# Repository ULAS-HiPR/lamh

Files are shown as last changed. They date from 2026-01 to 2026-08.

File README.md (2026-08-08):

# Lámh

Lámh is the airbrake actuator node in [Ogma](https://sean-osullivan.com/projects/ogma/), the University of Limerick Aeronautics Society's modular avionics stack for high-powered rocketry.

## Role

- Drives four routed servo outputs through a PCA9685.
- Reads a physical arm input.
- Accepts time-limited actuator commands over the 500 kbit/s CAN bus.
- Enforces defined safe states when commands expire or communication is lost.

## Repository

- `hardware/` - KiCad design and manufacturing outputs.
- `firmware/` - embedded firmware, actuator probes, and tests.

## Status

Rev 1 firmware and hardware bring-up continue on [`ogma/flight-hardening`](https://github.com/ULAS-HiPR/lamh/tree/ogma/flight-hardening). Release-candidate firmware builds and software tests pass, but hardware-in-the-loop validation is still underway. Lámh is not yet flight-proven.

## Manufacturing support

Rev 1 PCB fabrication was sponsored through [EasyEDA Education](https://easyeda.com/education) and manufactured by [JLCPCB](https://jlcpcb.com/). The board was designed in KiCad and imported into EasyEDA Pro for the sponsorship and manufacturing workflow.

## More information

See the [Ogma project write-up](https://sean-osullivan.com/projects/ogma/) for the complete stack, bring-up work, and current status.

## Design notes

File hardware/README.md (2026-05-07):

# Hardware Notes

## PCA9685 servo outputs

The current Lamh PCB routes the PCA9685 outputs to four servo connectors:

| Connector | PCA9685 channel | Connector pin 1 | Connector pin 2 | Connector pin 3 |
| --- | ---: | --- | --- | --- |
| J4 | 0 | Signal | GND | 5v_SERVO |
| J6 | 2 | Signal | GND | 5v_SERVO |
| J2 | 4 | Signal | GND | 5v_SERVO |
| J3 | 6 | Signal | GND | 5v_SERVO |

The firmware demo currently sweeps channel 0, so plug the demo servo into J4.

## PCA9685 address

A0-A3 have pulldowns and solder jumpers to 3.3 V. For the default `0x40` address, leave those jumpers open. The firmware scans the PCA9685 hardware-address range at boot, so changed address jumpers should still work.

A4 and A5 are marked unconnected in the current PCB files. If I2C probing is unstable on a built board, strap U2 A4 and A5 low for a deterministic `0x40` address in the next hardware revision.

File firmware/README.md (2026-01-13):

# Lamh

Lamh is for any active control like airbrakes or canards. It will control servos.

## Set-Up

```bash
git clone git@github.com:ULAS-HiPR/lamh.git
cd lamh
git submodule update --init --recursive
```

## Libraries used:

### From Braiteoiri:

- Servo
- LED

### From Comheadan:

- CAN
- PWM

### Other:

- FreeRTOS

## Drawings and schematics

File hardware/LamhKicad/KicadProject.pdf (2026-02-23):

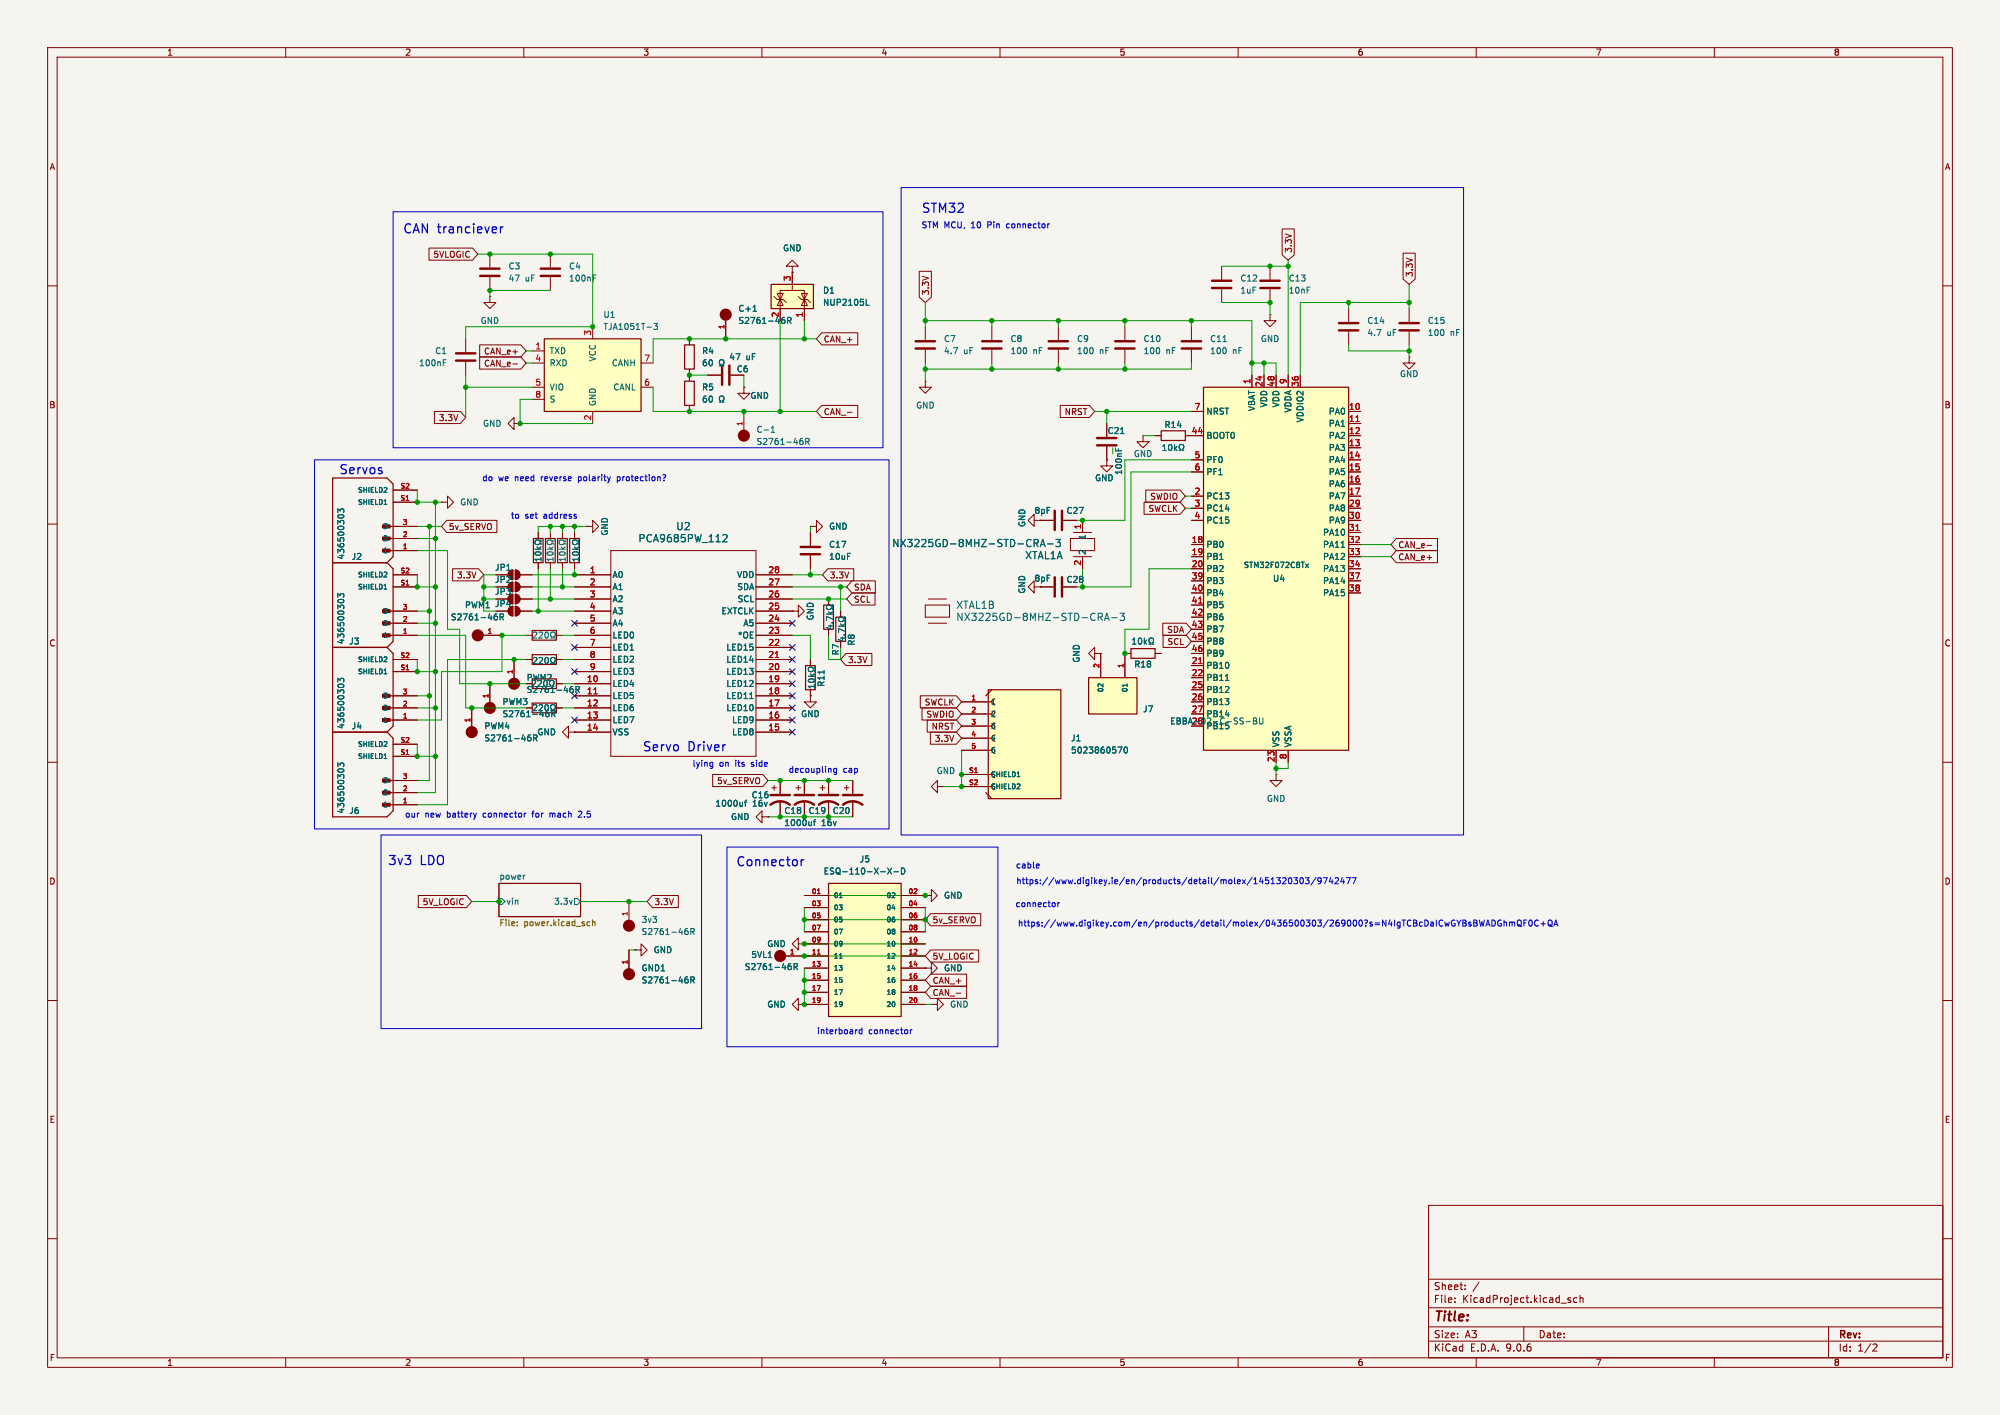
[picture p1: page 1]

STM32
STM MCU, 10 Pin connector

1 VDD 24 VDD 48 VSS 23 VDDA

1 GND R7 þÿ4.7k© R8þÿ4.7k© R11 þÿ10k© GND

lying on its side
1 GND GND

https://www.digikey.ie/en/products/detail/molex/1451320303/9742477

https://www.digikey.com/en/products/detail/molex/0436500303/269000?s=N4IgTCBcDaICwGYBsBWADGhmQF0C+QA

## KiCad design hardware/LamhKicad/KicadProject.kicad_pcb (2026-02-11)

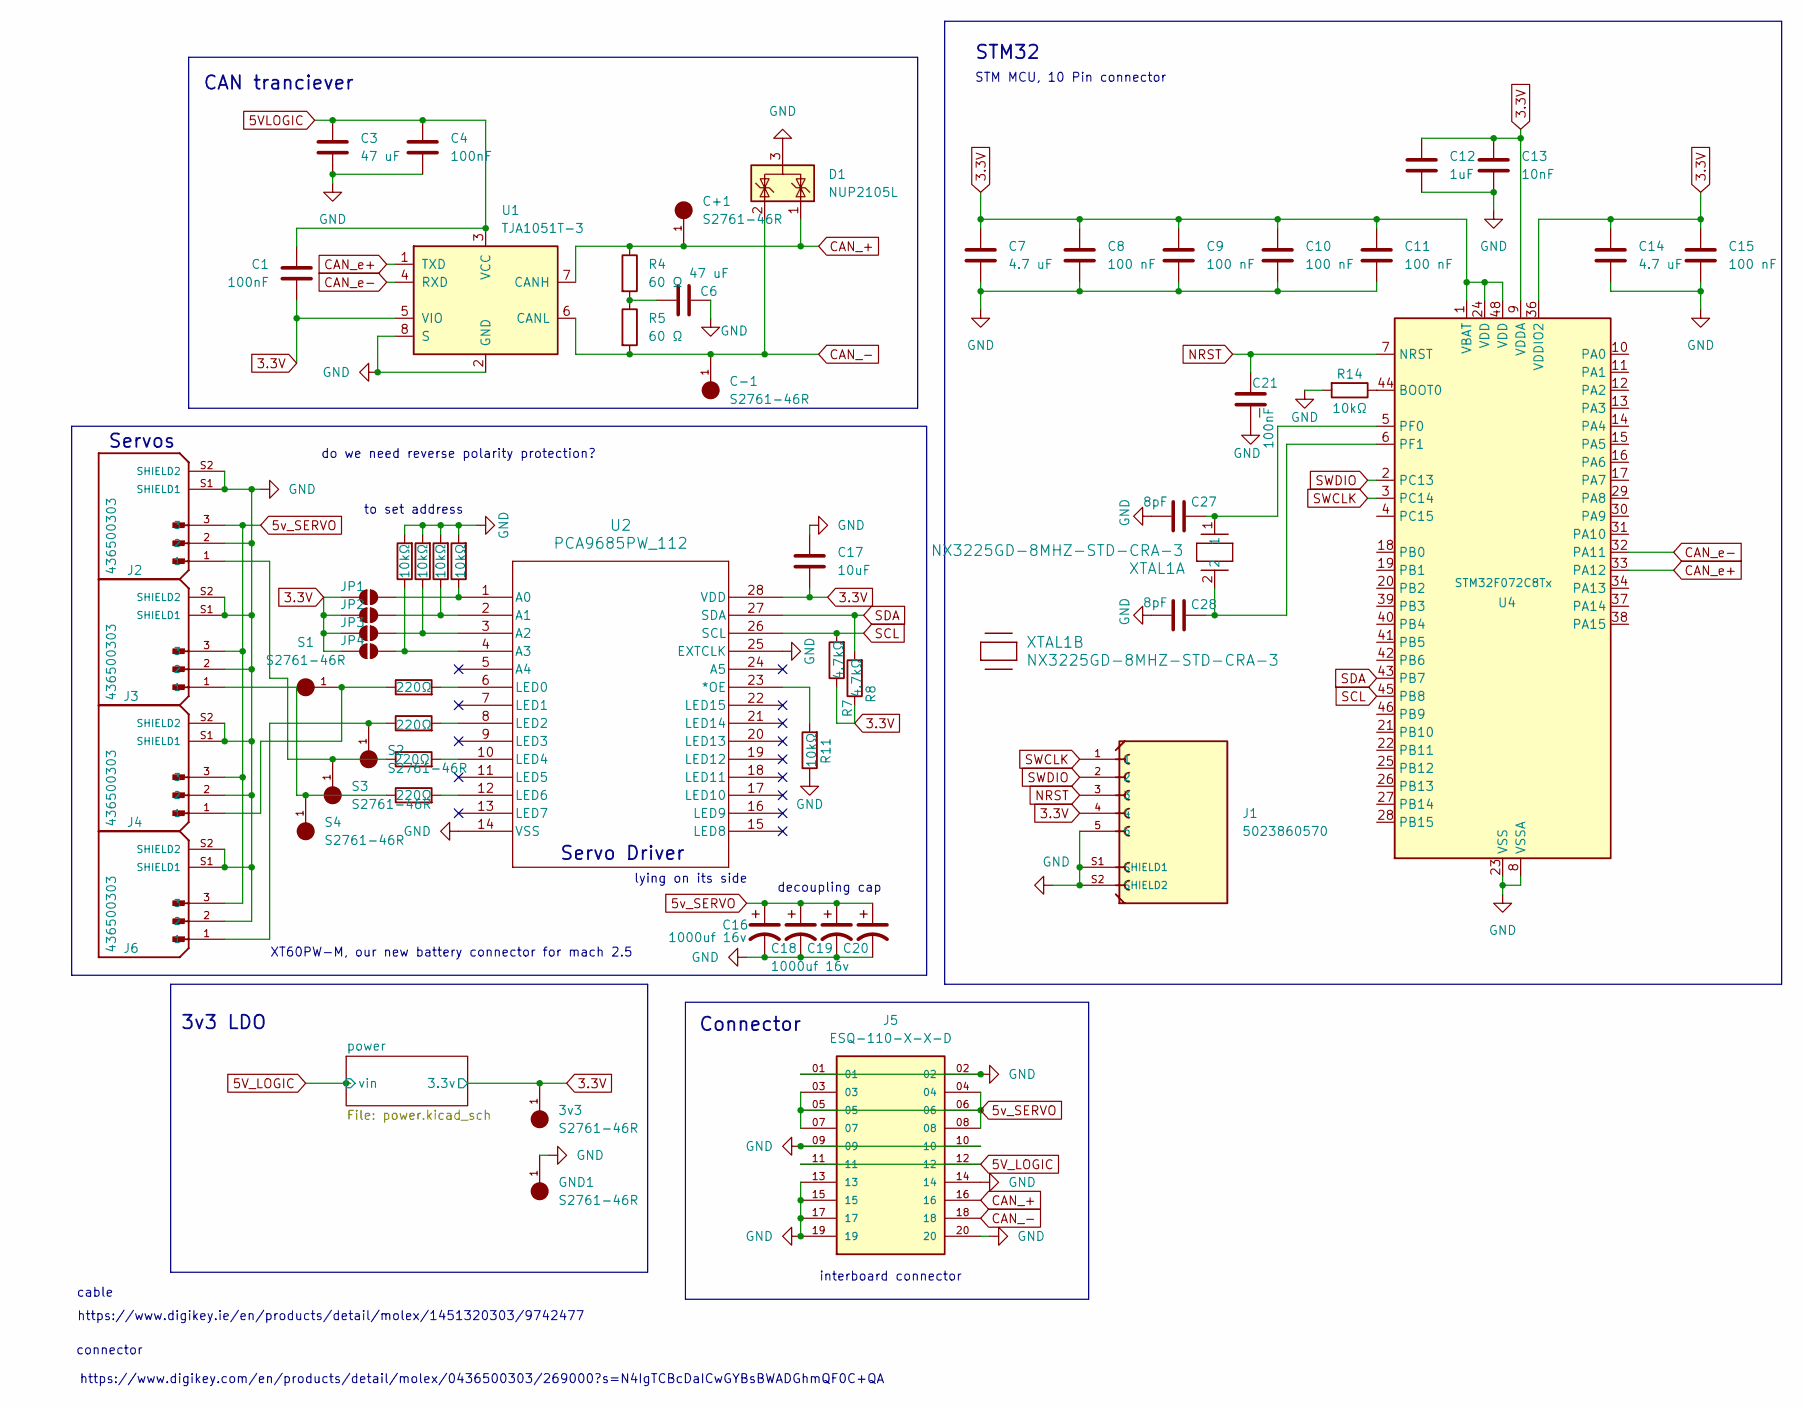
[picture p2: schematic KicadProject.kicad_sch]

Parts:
3v3: S2761-46R; HARWIN_S2761-46R; PARTREV 1
C1, C4, C21: 100nF; C_0402_1005Metric
C3, C6: 47 uF; C_0402_1005Metric
C7, C14: 4.7 uF; C_0402_1005Metric
C8, C9, C10, C11, C15: 100 nF; C_0402_1005Metric
C12: 1uF; C_0402_1005Metric
C13: 10nF; C_0402_1005Metric
C16, C18, C19, C20: 1000uf 16v; CP_Radial_D10.0mm_P5.00mm
C17: 10uF; C_0402_1005Metric
C27, C28: 8pF; C_0402_1005Metric
C+1: S2761-46R; HARWIN_S2761-46R; PARTREV 1
C-1: S2761-46R; HARWIN_S2761-46R; PARTREV 1
D1: NUP2105L; SOT-23
GND1: S2761-46R; HARWIN_S2761-46R; PARTREV 1
J1: 5023860570; MOLEX_5023860570; PARTREV F
J2, J3, J4, J6: 436500303; MOLEX_436500303; PARTREV F3
J5: ESQ-110-X-X-D; SAMTEC_ESQ-110-14-G-D; PARTREV NA
JP1, JP2, JP3, JP4: SolderJumper_2_Open; SolderJumper-2_P1.3mm_Open_TrianglePad1.0x1.5mm
R1, R2, R3, R6: 220Ω; R_0402_1005Metric
R4, R5: 60 Ω; R_0402_1005Metric
R7, R8: 4.7kΩ; R_0402_1005Metric
R9, R10, R11, R12, R13, R14: 10kΩ; R_0402_1005Metric
S1, S2, S3, S4: S2761-46R; HARWIN_S2761-46R; PARTREV 1
U1: TJA1051T-3; SOIC-8_3.9x4.9mm_P1.27mm
U2: PCA9685PW_112; TSSOP28_SOT361-1_NXP
U4: STM32F072C8Tx; LQFP-48_7x7mm_P0.5mm
XTAL1: NX3225GD-8MHZ-STD-CRA-3; XTAL_NX3225GD-8MHZ-STD-CRA-3_NDK

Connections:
3.3V: 3v3.1, C1.1, C7.1, C8.1, C9.1, C10.1, C11.1, C12.1, C13.1, C14.1, C15.1, C17.2, J1.4, JP1.1 (A), JP2.1 (A), JP3.1 (A), JP4.1 (A), R7.1, R8.1, U1.5 (VIO), U2.28 (VDD), U4.1 (VBAT), U4.9 (VDDA), U4.24 (VDD), U4.36 (VDDIO2), U4.48 (VDD); also elsewhere on the board
5VLOGIC: C1.2, C3.1, C4.1, U1.3 (VCC)
5V_LOGIC: J5.11, J5.12; also elsewhere on the board
5v_SERVO: C16.1, C18.1, C19.1, C20.1, J2.3, J3.3, J4.3, J5.03, J5.04, J5.05, J5.06, J5.07, J5.08, J6.3
CAN_+: C+1.1, D1.1 (K), J5.16, R4.1, U1.7 (CANH)
CAN_-: C-1.1, D1.2 (K), J5.18, R5.2, U1.6 (CANL)
CAN_e+: U1.1 (TXD), U4.33 (PA12)
CAN_e-: U1.4 (RXD), U4.32 (PA11)
GND: C3.2, C4.2, C6.2, C7.2, C8.2, C9.2, C10.2, C11.2, C12.2, C13.2, C14.2, C15.2, C16.2, C17.1, C18.2, C19.2, C20.2, C21.2, C27.1, C28.2, D1.3 (A), GND1.1, J1.5, J1.S1 (SHIELD1), J1.S2 (SHIELD2), J2.2, J2.S1 (SHIELD1), J2.S2 (SHIELD2), J3.2, J3.S1 (SHIELD1), J3.S2 (SHIELD2), J4.2, J4.S1 (SHIELD1), J4.S2 (SHIELD2), J5.01, J5.02, J5.09, J5.10, J5.13, J5.14, J5.15, J5.17, J5.19, J5.20, J6.2, J6.S1 (SHIELD1), J6.S2 (SHIELD2), R9.2, R10.2, R11.1, R12.2, R13.2, R14.2, U1.2 (GND), U1.8 (S), U2.14 (VSS), U2.25 (EXTCLK), U4.8 (VSSA), U4.23 (VSS), U4.35 (VSS), U4.47 (VSS); also elsewhere on the board
NRST: C21.1, J1.3, U4.7 (NRST)
unnamed: C6.1, R4.2, R5.1
unnamed: J2.1, R3.1, S3.1
unnamed: J3.1, R6.1, S4.1
unnamed: J4.1, R1.1, S1.1
unnamed: J6.1, R2.1, S2.1
unnamed: JP1.2 (B), R9.1, U2.1 (A0)
unnamed: JP2.2 (B), R10.1, U2.2 (A1)
unnamed: JP3.2 (B), R12.1, U2.3 (A2)
unnamed: JP4.2 (B), R13.1, U2.4 (A3)
unnamed: R11.2, U2.23 (*OE)
unnamed: R1.2, U2.6 (LED0)
unnamed: R2.2, U2.8 (LED2)
unnamed: R3.2, U2.10 (LED4)
unnamed: R6.2, U2.12 (LED6)
unnamed: R14.1, U4.44 (BOOT0)
unnamed: C27.2, U4.5 (PF0), XTAL1.1
unnamed: C28.1, U4.6 (PF1), XTAL1.2
SCL: R7.2, U2.26 (SCL), U4.45 (PB8)
SDA: R8.2, U2.27 (SDA), U4.43 (PB7)
SWCLK: J1.1, U4.3 (PC14)
SWDIO: J1.2, U4.2 (PC13)

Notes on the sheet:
Servo Driver
Servos
interboard connector
cable
3v3 LDO
CAN tranciever
STM32
decoupling cap
XT60PW-M, our new battery connector for mach 2.5
https://www.digikey.com/en/products/detail/molex/0436500303/269000?s=N4IgTCBcDaICwGYBsBWADGhmQF0C+QA
https://www.digikey.ie/en/products/detail/molex/1451320303/9742477
connector
Connector
lying on its side
to set address
do we need reverse polarity protection?
STM MCU, 10 Pin connector

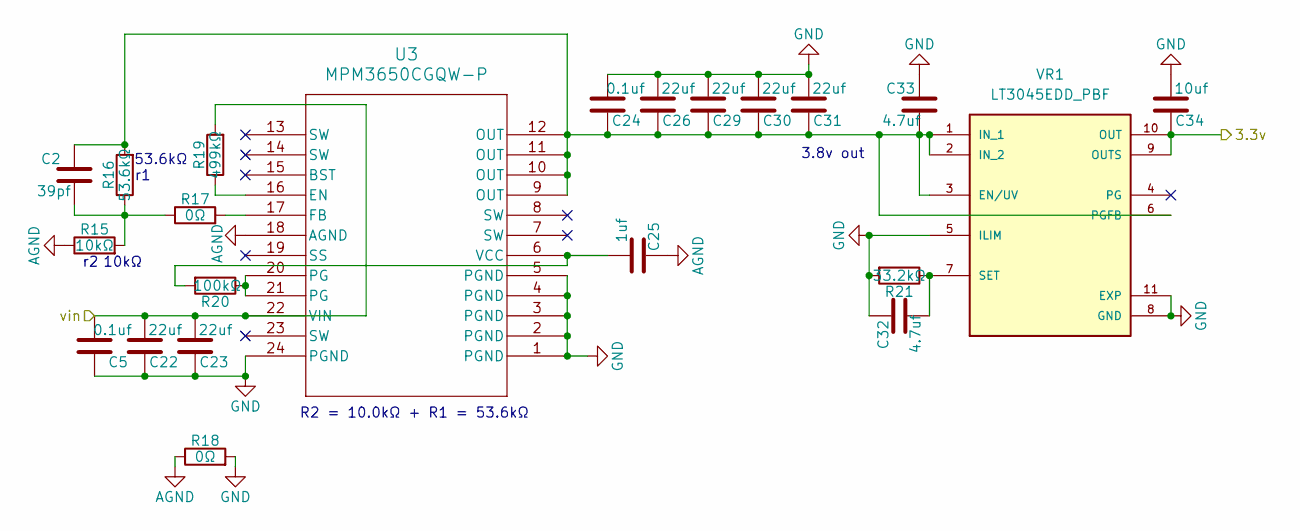
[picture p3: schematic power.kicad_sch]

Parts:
C2: 39pf; C_0402_1005Metric
C5, C24: 0.1uf; C_0402_1005Metric
C22, C23, C26, C29, C30, C31: 22uf; C_0402_1005Metric
C25: 1uf; C_0402_1005Metric
C32, C33: 4.7uf; C_0402_1005Metric
C34: 10uf; C_0402_1005Metric
R15: 10kΩ; R_0402_1005Metric
R16: 53.6kΩ; R_0402_1005Metric
R17, R18: 0Ω; R_0402_1005Metric
R19: 499kΩ; R_0402_1005Metric
R20: 100kΩ; R_0402_1005Metric
R21: 33.2kΩ; R_0402_1005Metric
U3: MPM3650CGQW-P; QFN-24_MPM3650_MNP
VR1: LT3045EDD_PBF; SON50P300X300X80-11N; PARTREV C

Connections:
3.3V: C34.1, VR1.9 (OUTS), VR1.10 (OUT); also elsewhere on the board
5V_LOGIC: C5.2, C22.2, C23.2, R19.2, U3.22 (VIN); also elsewhere on the board
AGND: C25.1, R15.1, R18.1, U3.18 (AGND)
GND: C5.1, C22.1, C23.1, C24.2, C26.2, C29.2, C30.2, C31.2, C32.1, C33.1, C34.2, R18.2, R21.2, U3.1 (PGND), U3.2 (PGND), U3.3 (PGND), U3.4 (PGND), U3.5 (PGND), U3.24 (PGND), VR1.5 (ILIM), VR1.8 (GND), VR1.11 (EXP); also elsewhere on the board
unnamed: C2.2, R15.2, R16.1, R17.1
unnamed: R20.1, U3.20 (PG), U3.21 (PG)
unnamed: R19.1, U3.16 (EN)
unnamed: R17.2, U3.17 (FB)
unnamed: C25.2, R20.2, U3.6 (VCC)
unnamed: C2.1, C24.1, C26.1, C29.1, C30.1, C31.1, C33.2, R16.2, U3.9 (OUT), U3.10 (OUT), U3.11 (OUT), U3.12 (OUT), VR1.1 (IN_1), VR1.2 (IN_2), VR1.3 (EN/UV), VR1.6 (PGFB)
unnamed: C32.2, R21.1, VR1.7 (SET)

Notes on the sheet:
10kΩ
53.6kΩ
R2 = 10.0kΩ + R1 = 53.6kΩ
3.8v out

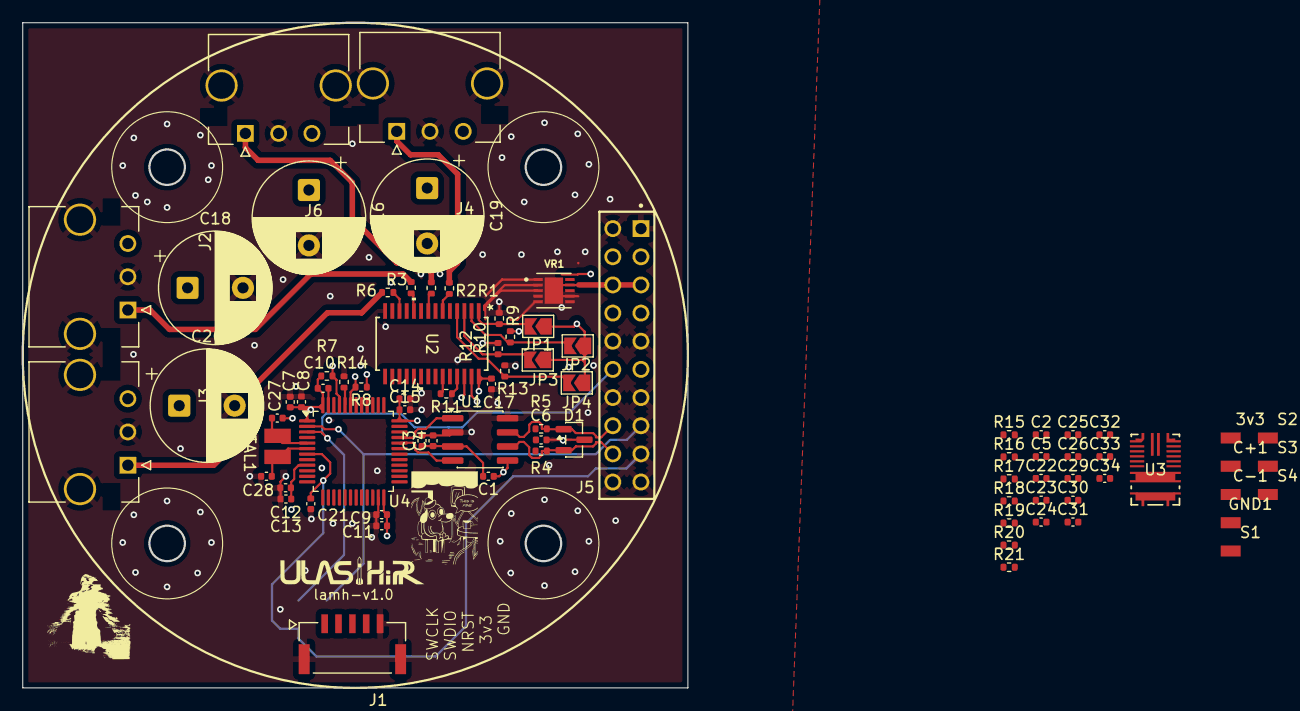
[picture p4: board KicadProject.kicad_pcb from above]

Board: 6 copper layers, 60.0 x 60.0 mm, 80 parts (0 on the bottom side), 39 nets.

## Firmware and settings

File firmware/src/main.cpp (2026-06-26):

#if F4
#include "stm32f4xx_hal.h"
#include "platform/stm_f4.h"
#endif
#if F0
#include "stm32f0xx_hal.h"
#include "platform/stm_f0.h"
#endif
#include "cmsis_os.h"
#include "FreeRTOS.h"
#include "task.h"
#include "platform/error_handler.h"
#include "platform/hal_time.h"

#include <data.h>
#include <sensor.h>
#include <I2C/I2C_STM.h>
#include <Servo/servo.h>
#include <Servo/PCA9685.h>
#include <CAN/CAN_Handler.h>
#if F4
#include <CAN/CAN_Mock.h>
#elif F0
#include <CAN/CAN_STM.h>
#endif

#include "tasks/canards_controller.h"
#include "tasks/CAN_task.h"

#include <stdint.h>


void SystemClock_Config(void);


const osMessageQueueAttr_t canQueue_attributes = {
  .name = "canQueue"
};

const osMessageQueueAttr_t loggingQueue_attributes = {
  .name = "loggingQueue"
};

int main(void)
{
  HAL_Init();
  SystemClock_Config();

  MX_GPIO_Init();
  MX_I2C1_Init();

  osKernelInitialize();
  printf("BOOT 1\n");

  //bool init_status = true;
  //shifting occuring in the I2C_STM class, so no need to shift here -> shouldnt do that imo
  I2C_Handler* i2c = new I2C_STM(&hi2c1, SERVO_ADDR);
  Servo* servo = new PCA9685Servo(*i2c, 0, SERVO_ADDR);

  #if F4
   CAN_Handler* canbus = new CAN_MOCK();
  #elif F0
    MX_CAN_Init();
    CAN_Handler* canbus = new CAN_STM(&hcan);
    bool can_init_status = canbus->init();
  #endif

  osMessageQueueId_t canInQueueHandle =
    osMessageQueueNew(8, sizeof(flight_data), &canQueue_attributes);
  osMessageQueueId_t canOutQueueHandle =
    osMessageQueueNew(8, sizeof(canards_raw), &loggingQueue_attributes);

  static task::Canards_Controller canards_controller(*servo, ACTIVE_PIN, ACTIVE_GPIO_PORT, 2275.0f, canInQueueHandle, canOutQueueHandle);
  static task::CAN_task can_task(*canbus, canInQueueHandle, canOutQueueHandle);

  
  can_task.run();
  canards_controller.run();

  osKernelStart();

  // never get here 
  while (1)
  {
    HAL_Delay(1000);
  }
}



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


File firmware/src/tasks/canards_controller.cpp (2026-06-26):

#include "canards_controller.h"
#include <ratio>

namespace task {

void Canards_Controller::run() {
    taskHandle_ = osThreadNew(&Canards_Controller::StartCanardsControllerEntry,
                              this,
                              &task_attributes);
}

void Canards_Controller::StartCanardsControllerEntry(void *argument) {
    auto *self = static_cast<Canards_Controller*>(argument);
    if (self) {
        self->StartCanardsController();
    }
}

void Canards_Controller::StartCanardsController() {
    bool servo_init = servo_.init();

    // start at centre so servo doesn't snap on boot
    servo_.set_position(180);
    osDelay(1000);
    servo_.set_position(15);

    flight_data flight_data_in;

    for (;;) {
        osStatus_t status;
        status = osMessageQueueGet(can_queue_, &flight_data_in, NULL, 10U);   // wait for message

        if (status == osOK) {
            printf("Received CAN data: %d\n", flight_data_in.state);            
            canards_raw canards_data = run_canards_controller(flight_data_in.core_data.imu, flight_data_in.core_data.barometer, flight_data_in.prediction);
            HAL_GPIO_ReadPin(active_port_, active_pin_) ? canards_data.active = true : canards_data.active = false;

            if (safety_check(canards_data.active, flight_data_in.core_data.imu)) {
                servo_.set_position(canards_data.servo_angle);
            } else {
                stop_action();  // keep neutral
            }

        osMessageQueuePut(logger_queue_, &canards_data, 0, 0);
        }
        osDelay(CANARDS_DELAY_MS);  
    }
}

// to change to airbrakes algo
canards_raw Canards_Controller::run_canards_controller(const imu_data& imu, const baro_data& baro, const prediction_data& pred) {
    // density of air = pressure / (R * temperature)
    float rho = baro.pressure / (287.058f * (baro.temperature + 273.15f));  // kg/m^3

    // dt since last call 
    uint32_t now = HAL_GetTick();
    float dt = (now - last_airbrake_time_ms_) * 0.001f;
    last_airbrake_time_ms_ = now;
    if (dt <= 0.0f) {
        dt = 0.02f;   
    }

    float speedOfSound = sqrt(401.87f * (baro.temperature + 273.15f));  // m/s, speed of sound in air at given temperature
    float mach = pred.velocity / speedOfSound;
    float machClamped = fmaxf(0.3f, fminf(1.1f, mach));


    float d = last_deployment_;
    float M = machClamped;
    float PreviousCd =
        (-0.0027f * d)
        + (0.0197f * d * M)
        - (0.0394f * d * powf(M, 2.0f))
        + (0.0246f * d * powf(M, 3.0f))
        + (0.0035f * powf(d, 2.0f))
        - (0.0086f * powf(d, 2.0f) * M)
        + (0.0179f * powf(d, 2.0f) * powf(M, 2.0f))
        - (0.0118f * powf(d, 2.0f) * powf(M, 3.0f))
        + 0.006424f;
    

    PreviousCd = fmaxf(PreviousCd, CD_FLOOR);

    float aDrag = (rho * PreviousCd * pred.velocity * pred.velocity) / (2.0f * mass);

    if (fabsf(pred.velocity) < 1.0f) {
        servo_angle = 180.0f;  // airbrakes stowed
        return {0.0f, 0.0f, servo_angle};
    }

    float Kp = (4.0f * mass * powf(g + aDrag, 2.0f)) / (rho * PreviousCd * areaMax * powf(pred.velocity, 4.0f));
    float Kd = (8.0f * zeta * mass * powf(g + aDrag, 2.0f)) / (rho * PreviousCd * areaMax * powf(pred.velocity, 4.0f));
    
    // Apogee prediction
    // ApogeePredicted = CurrentAltitude + VerticalVelocity^2 / (2*(g+aDrag))
    float ApogeePredicted = baro.altitude + (pred.velocity * pred.velocity) / (2.0f * (g + aDrag));

    float Error = ApogeePredicted - apogeeDesired;
    float ErrorRate = (Error - previous_error_) / dt;
    previous_error_ = Error;

    float Proportional = Kp * Error;
    float Derivative = Kd * ErrorRate;
    float output = Proportional + Derivative;

    // Clamp output (deployment level) 0..1
    output = fmaxf(0.0f, fminf(1.0f, output));

    // Remember deployment level for next iteration's PreviousCd calc
    last_deployment_ = output;

    // Map deployment level [0,1] -> servo angle: 180 = fully in, 15 = fully out
    servo_angle = 180.0f + output * (15.0f - 180.0f);

    return {Kp, Kd, servo_angle};
};

void Canards_Controller::stop_action() {
    servo_.set_position(180);   //neutral position
};


bool Canards_Controller::safety_check(bool active, const imu_data& imu) {
    // only use airbrakes when cots computer signals coasting
    if (active == false) {
        return false; 
    }
    
    // check tilt angle from IMU, if too large, stop the canards to prevent further instability
    // for airbrakes indicated 1 has broken
    if (imu.acceleration.x > 50.0f || imu.acceleration.x < -50.0f) {
        return false; 
    }
    return true;

}
}

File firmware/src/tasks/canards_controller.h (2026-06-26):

#pragma once
#include <atomic>
#include <cstdint>
#if F4
#include "stm32f4xx_hal.h"
#include "platform/stm_f4.h"
#endif
#if F0
#include "stm32f0xx_hal.h"
#include "platform/stm_f0.h"
#endif
#include "platform/hal_time.h"


#include "cmsis_os.h"
#include <math.h>
#include <cstdio>
#include <cstdint>
#include <data.h>
#include <Servo/servo.h>

#define CANARDS_DELAY_MS 100
// this is actully for airbrakes
//180 = in
//0 = out

namespace task{
class Canards_Controller {
    public:
        Canards_Controller(
                      Servo& servo,
                      int8_t active_pin,  // should make a pin wrapper but whatever
                      GPIO_TypeDef* active_port,
                      float apogeeDesired,
                      osMessageQueueId_t can_queue,
                      osMessageQueueId_t logger_queue)
            : 
              servo_(servo),
              active_pin_(active_pin),
              active_port_(active_port),
              apogeeDesired(apogeeDesired),
              can_queue_(can_queue),
              logger_queue_(logger_queue),
              taskHandle_(nullptr){};
              
        void run();

    private:
        Servo& servo_;
        int8_t active_pin_;
        GPIO_TypeDef* active_port_;
        float apogeeDesired{2000.0f}; // desired apogee in meters
        osMessageQueueId_t can_queue_;
        osMessageQueueId_t logger_queue_;

        void StartCanardsController();
        static void StartCanardsControllerEntry(void *argument);
        canards_raw run_canards_controller(const imu_data& imu, const baro_data& baro, const prediction_data& pred);
        float get_rocket_angle(const imu_data& imu);
        void stop_action();
        bool safety_check(bool active, const imu_data& imu);
        void get_up_direction();

        

        // controller state
        float last_deployment_ = 0.0f;   // previous step's clamped output (d in Artem's formula)
        float previous_error_ = 0.0f;    // for ErrorRate
        uint32_t last_airbrake_time_ms_ = 0;
        float servo_angle = 180.0f;


        static constexpr float mass = 14.544f; //kg
        static constexpr float g = 9.80665f;   // m/s^2
        static constexpr float speedOfSound = 343.0f;  // m/s
        static constexpr float areaMax = 0.00388f;    // m^2 (maximum deployed area)
        static constexpr float zeta = 1; // damping ratio
        static constexpr float CD_FLOOR = 1e-3f;  // minimum drag coefficient
        
  

      

        osThreadId_t taskHandle_;

        const osThreadAttr_t task_attributes {
            "CanardsController",
            0,
            nullptr,
            0,
            nullptr,
            512,        // 512 byte stack
            osPriorityHigh,
            0,
            0
        };
    };

}

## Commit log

2026-01-15 Schematic for Lamh
    [KicadProject.kicad_sch]
2026-01-15 Schematic update
    [Foinse.kicad_sch, KicadProject.kicad_pcb, KicadProject.kicad_sch]
2026-01-20 Some fixes to PCB editor conversion
    [KicadProject.kicad_pcb, KicadProject.kicad_sch]
2026-01-20 Fixed all footprints
    [KicadProject.kicad_pcb, KicadProject.kicad_sch]
2026-01-21 cleaning up
    [KicadProject.kicad_pcb, KicadProject.kicad_sch]
2026-01-22 updates, now just need the connector
    [KicadProject.kicad_sch]
2026-01-22 progs, yes
    [KicadProject.kicad_pcb, KicadProject.kicad_sch]
2026-01-22 added missing 3d models
    [KicadProject.kicad_pcb, KicadProject.kicad_sch]
2026-01-22 ready to route
    [KicadProject.kicad_pcb, KicadProject.kicad_sch]
2026-01-22 fixed the connector
    [KicadProject.kicad_pcb, KicadProject.kicad_sch]
2026-01-23 minor changes
    [KicadProject.kicad_pcb, KicadProject.kicad_sch]
2026-01-27 added links to servo connectors
    [KicadProject.kicad_sch]
2026-01-30 thermal expansion vias
    [KicadProject.kicad_pcb, KicadProject.kicad_sch]
2026-02-11 mockup done, must finish routing
    [KicadProject.kicad_pcb, KicadProject.kicad_sch, power.kicad_sch]
2026-02-20 clean asf
    [Foinse.kicad_sch, KicadProject.kicad_sch, power.kicad_sch]
2026-02-23 ready for review the twost
    [KicadProject.kicad_sch, power.kicad_sch]
2026-02-27 ready to go, nearly
    [KicadProject-B_Cu.gbr, KicadProject-B_Mask.gbr, KicadProject-B_Paste.gbr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]
2026-03-01 ready 2 order
    [KicadProject-B_Cu.gbr, KicadProject-B_Mask.gbr, KicadProject-B_Paste.gbr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]
2026-04-05 Adding telemetry basic task and basic logical flow to code
2026-04-05 Adding in servo to state machine and cleaning up ; & task namespace
2026-04-05 Starting to solve errors for base abstracted iteration
    [main.cpp, stm_f4.h]
2026-04-05 creating base tasks for acutal canards board
2026-04-29 Servo test
2026-04-30 progress on the servo front
2026-04-30 servo lives
2026-06-17 feat: added active pin and logic for airbrakes activation
2026-06-22 fix: stripping back to isolate CAN
    [canards_controller.cpp, canards_controller.h, main.cpp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]
2026-06-24 fix: adding rocket cd
    [canards_controller.cpp]
